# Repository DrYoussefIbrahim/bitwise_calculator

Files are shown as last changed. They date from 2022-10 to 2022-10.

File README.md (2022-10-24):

<html>

<h1> Bitwise Calculator Project </h1>
<subtitle> Author: Youssef Ibrahim - 24/October/2022 </subtitle>

<h2> Introduction </h2>
This is a pet project of mine where I aim to recreate the programming calcualtor function in Windows in hardware. The build features my favourite 5x7 LED matrices - the LTP-305G. The key matrix is based around the Cherry MX blue tactile keys for my pleasure.

<h2> Hardware description </h2>
This is a bare-board design as I prefer the minimalist aesthetic.

The hardware is dvided into two boards:
<ul>
<li> The key board - The main board. Houses the keys and microcontroller</li>
<li> The display board - Houses the LTP-305G modules and their drivers </li>
</ul>
The boards are combined into one PCB separated by a ratbite to simplify ordering from your favourite PCB fab house.

<h3> The key board </h3>
This sub-assembly consists of:
<ul>
<li> 21 Cherry MX blue tactile keys</li>
<li> The microcontroller - ATMEGA328PB (Of course!)</li>
<li> 74HC165 Parallel-in/Serial-out shift register - For key matrix multiplexing</li>
<li> Micro USB socket - for power only</li>
<li> I2C and power pads - for connection to the display board via a 4-core ribbon cable</li>
</ul>

<h3> The display board </h3>
This sub-assembly consists of:
<ul>
<li> 4 x IS31FL3730 LED matrix drivers - chained on a single I2C bus. All four I2C address configs are used</li>
<li> 8 x DIP 14 sockets - To receive the LTP-305G matricies</li>
<li> Power and I2C pads - To connect to the key board</li>
</ul>

<h2> Mode of operation </h2>
<p>The controller continously scans the key matrix using the 74HC165 shift register. Key inputs are parsed accordingly in software and the display is updated via the I2C interface. Simple, really! </p>

<p>All the magic happens in the software which implements the calculator function as well as drives the display animations. One of the keys on the key matrix is wired directly to the micro to serve as a wake-up interrupt since this isn't straight forward to implement using the shift register. This power-down feature is not currently implemented. </p>

<p> This project is still a work in progress. </p>

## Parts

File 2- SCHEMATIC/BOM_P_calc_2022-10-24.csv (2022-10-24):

ID | Name | Designator | Footprint | Quantity | Manufacturer Part | Manufacturer
1 | 1uF | C1 | C1206 | 1 | CL31B105KBHNNNE | SAMSUNG
2 | 4.7uF | C2 | C0402 | 1 | CL05A475MP5NRNC | SAMSUNG
3 | 100nF | C3,C4,C5,C8,C11,C12,C14,C16 | C0402 | 8 | CL05B104KB54PNC | Samsung Electro-Mechanics
4 | 10pF | C6,C7 | C0402 | 2 | CL05C100JB5NNNC | SAMSUNG
5 | 10uF | C9 | C1206 | 1 | CL31A106KBHNNNE | SAMSUNG
6 | BAS416,115 | D1,D2,D3,D4 | SOD-323_L1.8-W1.3-LS2.5-RD | 4 | BAS416,115 | Nexperia
7 | TPD4E05U06QDQARQ1 | D5 | USON-10_L2.5-W1.0-P0.50-BL | 1 | TPD4E05U06QDQARQ1 | TI
8 | 10kΩ | R1,R2,R3,R4,R5,R8,R9,R10,R11,R12,R13 | R0402 | 11 | 0402WGF1002TCE | UniOhm
9 | 1K | R6,R7 | R0402 | 2 | 0402WGF1001TCE | UniOhm
10 | DS1001-01-14BT1NSF6X-JKB | SK1,SK2,SK3,SK4,SK5,SK6,SK7,SK8 | DIP-14_L17.8-W10.2-P2.54-BL | 8 | DS1001-01-14BT1NSF6X-JKB | CONNFLY
11 | CHERRY MX BLUE | SW1,SW2,SW3,SW4,SW5,SW6,SW7,SW8,SW9,SW10,SW11,SW12,SW13,SW14,SW15,SW16,SW17,SW18,SW19,SW20,SW21 | CHERRY MX BLUE | 21
12 | ATMEGA328PB-AU | U1 | TQFP-32_L7.0-W7.0-P0.80-LS9.0-BL | 1 | ATMEGA328PB-AU | MICROCHIP
13 | 74HC165D,653 | U2 | SOIC-16_L9.9-W3.9-P1.27-LS6.0-BL | 1 | 74HC165D,653 | Nexperia
14 | IS31FL3730-QFLS2-TR | U3,U4,U5,U6 | QFN-24_L4.0-W4.0-P0.50-TL-EP2.7 | 4 | IS31FL3730-QFLS2-TR | Lumissil Microsystems
15 | 16MHz | X1 | OSC-SMD_4P-L3.2-W2.5-BL | 1 | X322516MLB4SI | YXC

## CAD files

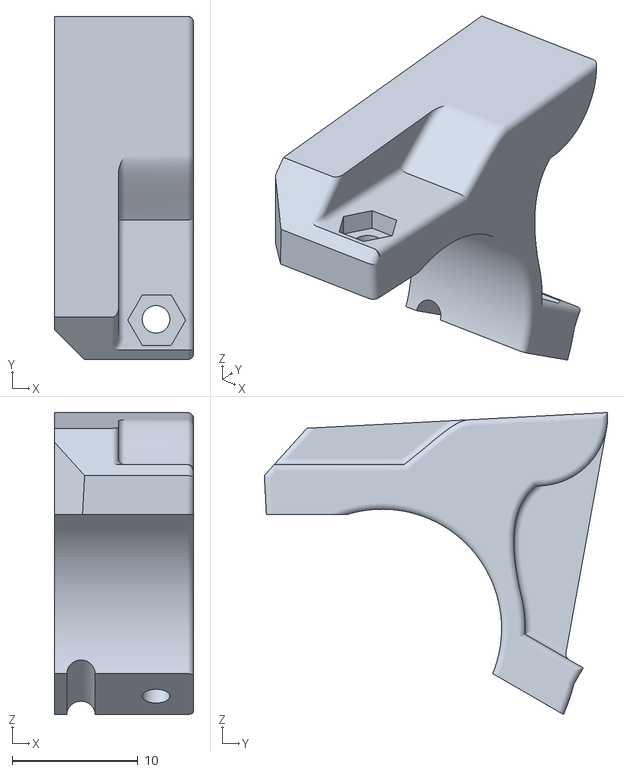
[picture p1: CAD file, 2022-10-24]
4- STL/LEFT SUPPORT(Mirror).stl
11.1 x 27.3 x 24.0

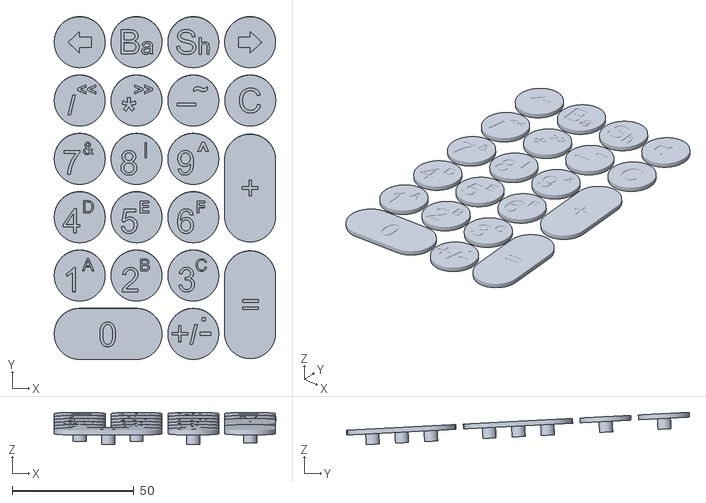
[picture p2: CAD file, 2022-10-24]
4- STL/P_calc_keys.stl
91.1 x 140.9 x 13.3

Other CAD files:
4- STL/RIGHT SUPPORT.stl

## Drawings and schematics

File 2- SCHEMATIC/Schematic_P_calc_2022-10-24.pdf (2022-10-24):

# DS 10 D0 11 D1 12 D2 13 D3 14 CE# 15 VCC 16

# Shift Register

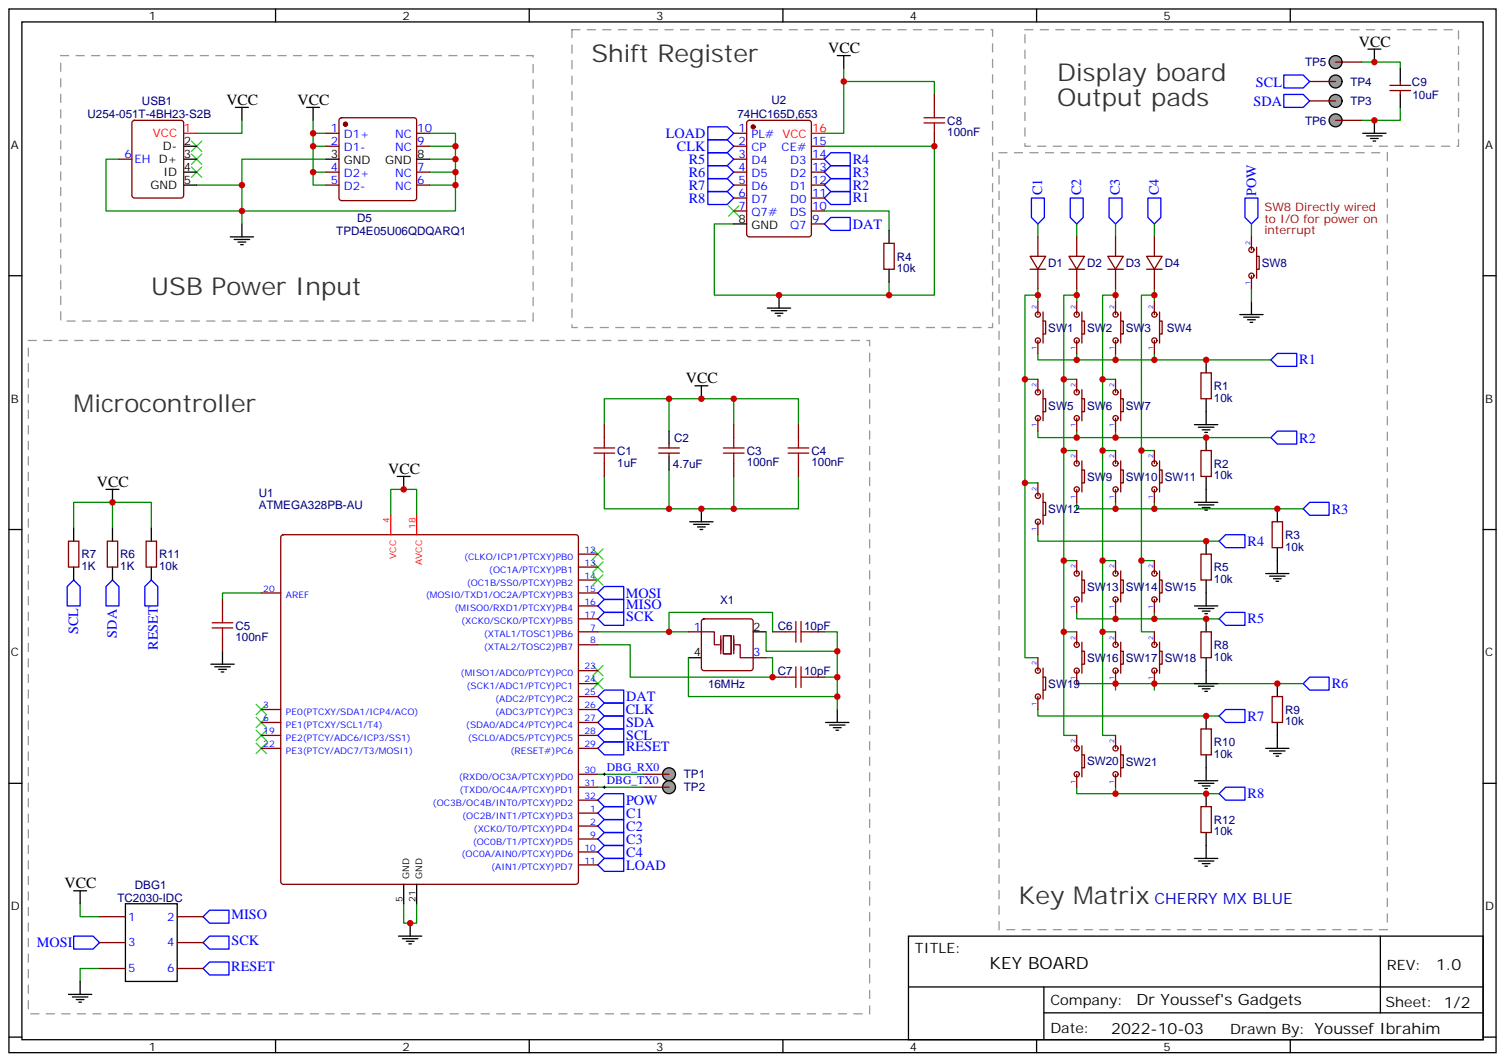
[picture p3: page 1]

SW8 Directly wired
to I/O for power on
interrupt

Key Matrix CHERRY MX BLUE

Company: Dr Youssef's Gadgets

Drawn By: Youssef Ibrahim

# LED Matrices 1 and 2

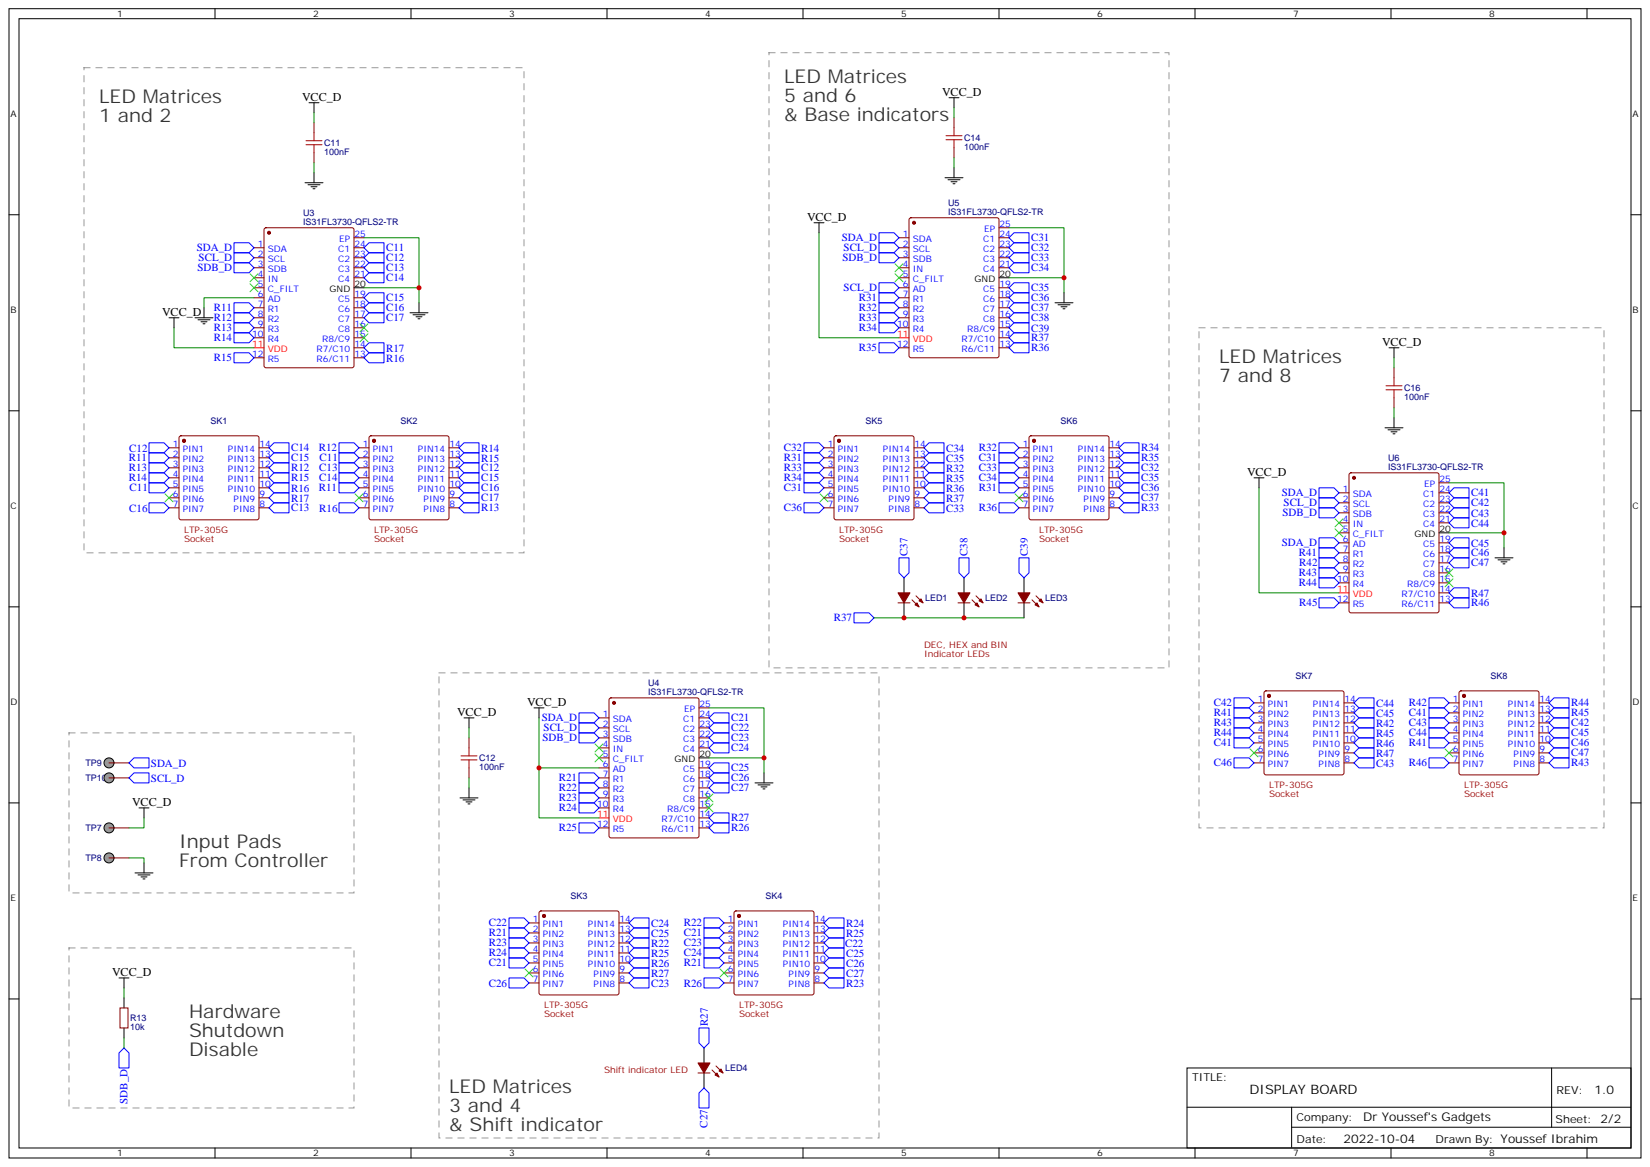
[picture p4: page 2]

DEC, HEX and BIN
Indicator LEDs

Company: Dr Youssef's Gadgets

Drawn By: Youssef Ibrahim

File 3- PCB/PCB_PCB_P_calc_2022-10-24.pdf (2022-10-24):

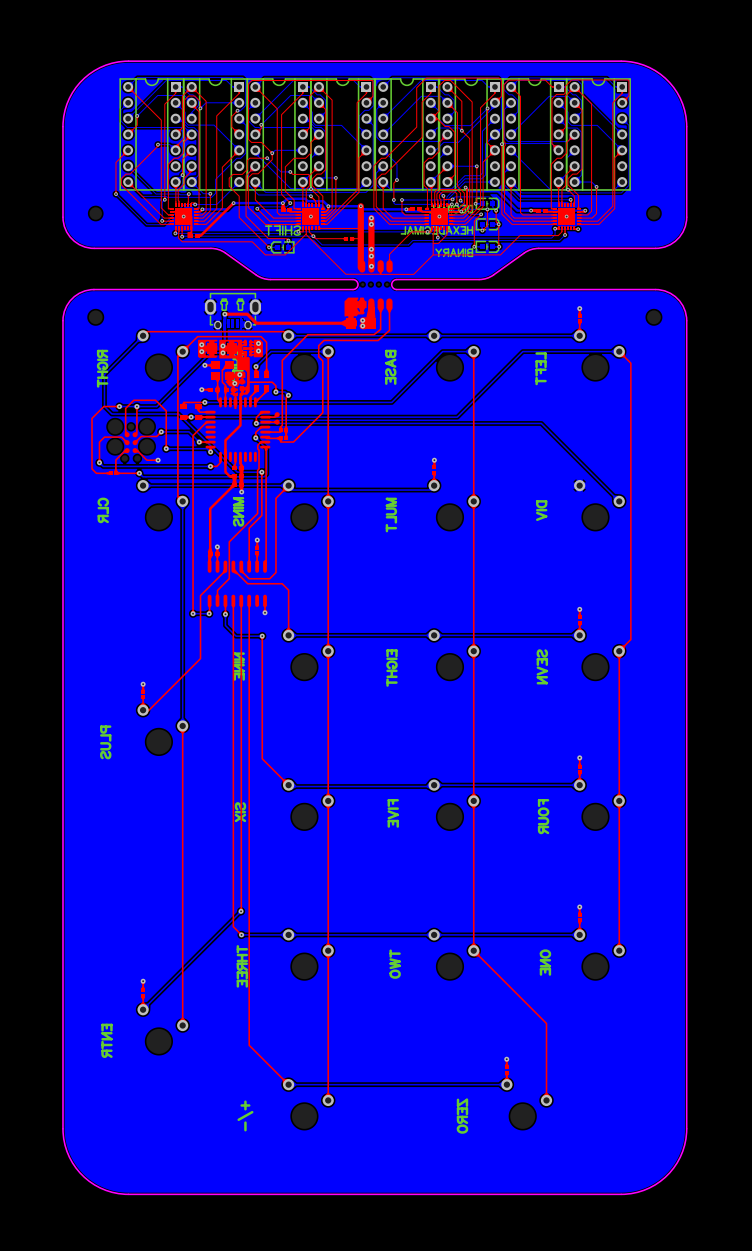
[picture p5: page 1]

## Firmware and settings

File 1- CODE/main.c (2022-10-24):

/*

Created: 12/10/2022 16:50:48
Author : Youssef Ibrahim

Bitwise Claculator (c) by Youssef Ibrahim

Bitwise Claculator is licensed under a
Creative Commons Attribution-ShareAlike 4.0 International License.

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
*/

#define F_CPU 16000000UL

#include <avr/io.h>
#include <util/delay.h>
#include <avr/interrupt.h>
#include "IS31FL3730.h"
#include "key_matrix.h"

void update_reg();
volatile uint8_t head = 10;
volatile uint8_t view = 10;
volatile uint32_t reg = 0;
volatile uint32_t regB = 0;
uint32_t regC = 0;
uint8_t valid = 0;
volatile uint8_t operation = 0;
volatile uint8_t execute = 0;

ISR(INT0_vect) {
	EIMSK &= ~0b00000001;
	if(shift_state == 1){
		reg <<= 1;
		update_reg();
		EIMSK |= 0b00000001;
		} else {
		operation = 4;
		execute = 0;
		regB = reg;
		IS31_clear();
		view = 10;
		head = 10;
		reg = 0;
	}
}

int main(void)
{
	TWI_Setup();
	EICRA = 0b00000000;
	EIMSK = 0b00000001;
	sei();
	IS31_begin();
	IS31_setMaxCurrent(11);
	IS31_setBrightness(128);
	key_begin();
	IS31_setBase(1);
	
	while (1)
	{
		while(key_scan() == -1);
		TWI_Reset();
		
		uint8_t key_input= key_scan();
		
		switch(key_input){
			case 10:
			break;
			
			case 11:
			if(execute != 1){
				regC = reg;
				execute = 1;
			}
			switch(operation){
				case 0:
				break;
				
				case 1: // Add
				regB += regC;
				break;
				
				case 2: // Multiply
				regB *= regC;
				break;
				
				case 3: // Subtract
				if(regB > regC){
					regB -= regC;
					} else {
					regB = 0;
				}
				break;
				
				case 4:
				regB /= regC;
				EIMSK = 0b00000001;
				break;
				
				case 5: // Bitwise AND
				regB &= regC;
				break;
				
				case 6: // Bitwise OR
				regB |= regC;
				break;
				
				case 7: // Bitwise XOR
				regB ^= regC;
				break;
				
				case 8: // Modulo
				regB %= regC;
				break;
				
				default:
				break;
			}
			reg = regB;
			update_reg();
			EIMSK = 0b00000001;
			break;
			
			case 12:
			operation = 1;
			execute = 0;
			regB = reg;
			IS31_clear();
			view = 10;
			head = 10;
			reg = 0;
			break;
			
			case 13:
			if(shift_state == 1){
				reg >>= 1;
				update_reg();
				} else {
				operation = 2;
				execute = 0;
				regB = reg;
				IS31_clear();
				view = 10;
				head = 10;
				reg = 0;
			}
			break;
			
			case 14:
			if(shift_state == 1){
				uint8_t mx = 0;
				uint32_t scanner = 1;
				for(uint8_t bt = 0; bt < 32 ; bt++){
					if(reg & (scanner<<bt)){
						mx = bt;
					}
				}
				mx++;
				scanner = 1;
				while(mx < 32){
					reg |= (scanner<<mx);
					mx++;
				}
				reg = ~reg;
				update_reg();
				} else {
				operation = 3;
				execute = 0;
				regB = reg;
				IS31_clear();
				view = 10;
				head = 10;
				reg = 0;
			}
			break;
			
			case 15:
			if(shift_state == 0){
			IS31_clear();
			view = 10;
			IS31_Update(view);
			head = 10;
			reg = 0;
			regB = 0;
			regC = 0;
			execute = 0;
			operation = 0;
			EIMSK = 0b00000001;
			} else {
				operation = 8;
				execute = 0;
				regB = reg;
				IS31_clear();
				view = 10;
				head = 10;
				reg = 0;
			}
			break;
			
			case 16:
			if(view<129 && (view + 40) < head){
				for(uint8_t i = 0; i < 5; i++){
					view++;
					IS31_Update(view);
					_delay_ms(10);
				}
			}
			break;
			
			case 17:
			IS31_setBase(base_state == 3? 1 : base_state + 1);
			update_reg();
			break;
			
			case 18:
			IS31_shift(!shift_state);
			break;
			
			case 19:
			if(view>=15){
				for(uint8_t i = 0; i < 5; i++){
					view--;
					IS31_Update(view);
					_delay_ms(10);
				}
			}
			break;
			
			default:
			valid = 0;
			if(shift_state == 1 && key_input > 6 ){
				switch(key_input){
					case 7:
					operation = 5;
					execute = 0;
					regB = reg;
					IS31_clear();
					view = 10;
					head = 10;
					reg = 0;
					break;
					
					case 8:
					operation = 6;
					execute = 0;
					regB = reg;
					IS31_clear();
					view = 10;
					head = 10;
					reg = 0;
					break;
					
					case 9:
					operation = 7;
					execute = 0;
					regB = reg;
					IS31_clear();
					view = 10;
					head = 10;
					reg = 0;
					break;
					
					default:
					break;
				}
			} else {
				switch(base_state){
					case 1:
					if(shift_state == 0 || key_input == 0){
						reg = (reg * 10) + key_input;
						IS31_drawChar(5, key_input);
						valid = 1;
					}
					break;
					
					case 2:
					if(shift_state == 0 || key_input == 0){
						reg = (reg * 16) + key_input;
						IS31_drawChar(5, key_input);
						valid = 1;
						} else if(key_input <= 6){
						reg = (reg * 16) + (key_input + 9);
						IS31_drawChar(5, key_input + 9);
						valid = 1;
					}
					break;
					
					case 3:
					if(key_input <= 1){
						reg = (reg * 2) + key_input;
						IS31_drawChar(5, key_input);
						valid = 1;
					}
					break;
				}
			}
			
			if(valid == 1){
				for(uint8_t i = 0; i < 5; i++){
					head++;
					IS31_scrollLeft();
					IS31_Update(view);
					_delay_ms(10);
				}
			}
			break;
		}
		
		while(key_scan() != -1);
	}
}

void update_reg(){
	for(uint8_t i = 0; i < 7; i++){
		IS31_scrollUp();
		IS31_Update(view);
		_delay_ms(10);
	}
	
	view = 10;
	if(reg != 0){
		for(uint8_t j = 0; j < 7; j++){
			head = 10;
			IS31_clear();
			uint32_t reg_temp = reg;
			uint32_t divisor = 1;
			uint8_t base = 0;
			switch(base_state){
				case 1:
				base = 10;
				break;
				
				case 2:
				base = 16;
				break;
				
				case 3:
				base = 2;
				break;
				
				default:
				break;
			}
			while(divisor <= (reg / base)){
				divisor *= base;
			}
			while(divisor > 0){
				for(uint8_t i = 0; i < 5; i++){
					IS31_scrollLeft();
					head++;
				}
				IS31_drawChar(10, reg_temp / divisor);
				reg_temp %= divisor;
				divisor /= base;
			}
			for(uint8_t k = 0; k < 6 - j; k++){
				IS31_scrollDown();
			}
			IS31_Update(view);
		}
	}
}

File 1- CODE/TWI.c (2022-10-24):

#include "TWI.h"

#define __TWI_SLA_W(address)	(address<<1)
#define __TWI_SLA_R(address)	((address<<1) | (1<<0))

#define F_CPU 16000000UL
//----- Prototypes ------------------------------//

//-----------------------------------------------//

//----- Functions -------------//
//Setup TWI hardware.
void TWI_Setup(void)
{
	//TWI pins as outputs
	PinMode(TWI_SDA, Output);
	PinMode(TWI_SCL, Output);
	//Activate internal pull-up resistors
	DigitalWrite(TWI_SDA, High);
	DigitalWrite(TWI_SCL, High);

	//Initialize TWI prescaler and bit rate
	TWSR0 = 0x00;	//Prescaler = 1
	TWBR0 = (uint8_t)(((F_CPU / F_SCL) - 16) / 2);
	//F_SCL = F_CPU / (16 + 2 * TWBR0 * PRESCALER)
	//TWBR0 = ((F_CPU / F_SCL) - 16) / (2 * PRESCALER)

	//Enable TWI  module
	TWCR0 = (1<<TWEN);
}

//Get TWI status. 
uint8_t TWI_Status(void)
{
	return (TWSR0 & 0xF8);
}

//Begin TWI transmission. 
uint8_t TWI_BeginTransmission(void)
{
	uint16_t i2c_count = 0;
	//Transmit START condition
	TWCR0 = (1<<TWINT) | (1<<TWSTA) | (1<<TWEN);

	//Wait for TWINT Flag set. This indicates that
	//the START condition has been transmitted.
	while ((!BitCheck(TWCR0, TWINT)) && (i2c_count < i2c_timeout)){
		i2c_count++;
	}

	//Return status register
	return (TWI_Status());
}

//End TWI transmission. 
void TWI_EndTransmission(void)
{
	uint16_t i2c_count = 0;
	//Transmit STOP condition
	TWCR0 = (1<<TWEN) | (1<<TWIE) | (1<<TWEA) | (1<<TWINT) | (1<<TWSTO);

	//Wait for stop condition to be executed on bus
	//TWINT is not set after a stop condition!
	while((BitCheck(TWCR0, TWSTO)) && (i2c_count < i2c_timeout)){
		i2c_count++;
	}
}

//Transmit data. 
uint8_t TWI_Transmit(const uint8_t Data)
{
	uint16_t i2c_count = 0;
	//Data to be transmitted
	TWDR0 = Data;

	//Start transmission
	TWCR0 = (1<<TWINT) | (1<<TWEN);

	//Wait data to be shifted
	while ((!BitCheck(TWCR0, TWINT)) && (i2c_count < i2c_timeout)){
		i2c_count++;
	}

	//Return status register
	return (TWI_Status());
}

//Wait until ACK received. 
uint8_t TWI_ReceiveACK(void)
{
	uint16_t i2c_count = 0;
	TWCR0 = (1<<TWINT) | (1<<TWEA) | (1<<TWEN);
	
	//Wait till reception is
	while ((!BitCheck(TWCR0, TWINT)) && (i2c_count < i2c_timeout)){
		i2c_count++;
	}

	//Return received data
	return TWDR0;
}

//Wait until NACK received. 
uint8_t TWI_ReceiveNACK(void)
{
	uint16_t i2c_count = 0;
	TWCR0 = (1<<TWINT) | (1<<TWEN);

	//Wait till reception is
	while ((!BitCheck(TWCR0, TWINT)) && (i2c_count < i2c_timeout)){
		i2c_count++;
	}

	//Return received data
	return TWDR0;
}

//Transmit packet to specific slave address. 
enum TWI_Status_t TWI_PacketTransmit(const uint8_t SLA, const uint8_t SubAddress, uint8_t *Packet, const uint8_t Length)
{
	uint8_t i, status;
	
	do
	{
		//Transmit START signal
		status = TWI_BeginTransmission();
		if ((status != MT_START_TRANSMITTED) && ((status != MT_REP_START_TRANSMITTED)))
		{
			status = TWI_Error;
			break;
		}

		//Transmit SLA+W
		status = TWI_Transmit(__TWI_SLA_W(SLA));
		if ((status != MT_SLA_W_TRANSMITTED_ACK) && (status != MT_SLA_W_TRANSMITTED_NACK))
		{
			status = TWI_Error;
			break;
		}

		//Transmit write address
		status = TWI_Transmit(SubAddress);
		if ((status != MT_DATA_TRANSMITTED_ACK) && (status != MT_DATA_TRANSMITTED_NACK))
		{
			status = TWI_Error;
			break;
		}
		//Transmit DATA
		for (i = 0 ; i < Length ; i++)
		{
			status = TWI_Transmit(Packet[i]);
			if ((status != MT_DATA_TRANSMITTED_ACK) && (status != MT_DATA_TRANSMITTED_NACK))
			{
				status = TWI_Error;
				break;
			}
		}

		//Transmitted successfully
		status = TWI_Ok;
	}
	while (0);

	//Transmit STOP signal
	TWI_EndTransmission();

	return status;
}

//Receive packet from specific slave address. 
enum TWI_Status_t TWI_PacketReceive(const uint8_t SLA, const uint8_t SubAddress, uint8_t *Packet, const uint8_t Length)
{
	uint8_t i = 0, status;

	do 
	{
		//Transmit START signal
		status = TWI_BeginTransmission();
		if ((status != MT_START_TRANSMITTED) && (status != MT_REP_START_TRANSMITTED))
		{
			status = TWI_Error;
			break;
		}

		//Transmit SLA+W
		status = TWI_Transmit(__TWI_SLA_W(SLA));
		if ((status != MT_SLA_W_TRANSMITTED_ACK) && (status != MT_SLA_W_TRANSMITTED_NACK))
		{
			status = TWI_Error;
			break;
		}

		//Transmit read address
		status = TWI_Transmit(SubAddress);
		if ((status != MT_DATA_TRANSMITTED_ACK) && (status != MT_DATA_TRANSMITTED_NACK))
		{
			status = TWI_Error;
			break;
		}

		//Transmit START signal
		status = TWI_BeginTransmission();
		if ((status != MR_START_TRANSMITTED) && (status != MR_REP_START_TRANSMITTED))
		{
			status = TWI_Error;
			break;
		}

		//Transmit SLA+R
		status = TWI_Transmit(__TWI_SLA_R(SLA));
		if ((status != MR_SLA_R_TRANSMITTED_ACK) && (status != MR_SLA_R_TRANSMITTED_NACK))
		{
			status = TWI_Error;
			break;
		}

		//Receive DATA
		//Read all the bytes, except the last one, sending ACK signal
		for (i = 0 ; i < (Length - 1) ; i++)
		{
			Packet[i] = TWI_ReceiveACK();
			status = TWI_Status();
			if ((status != MR_DATA_RECEIVED_ACK) && (status != MR_DATA_RECEIVED_NACK))
			{
				status = TWI_Error;
				break;
			}
		}
		//Receive last byte and send NACK signal
		Packet[i] = TWI_ReceiveNACK();
		status = TWI_Status();
		if ((status != MR_DATA_RECEIVED_ACK) && (status != MR_DATA_RECEIVED_NACK))
		{
			status = TWI_Error;
			break;
		}

		//Received successfully
		status = TWI_Ok;
	} 
	while (0);

	//Transmit STOP signal
	TWI_EndTransmission();
	
	return status;
}

//Set self slave address.
void TWI_SetAddress(const uint8_t Address)
{
	//Set TWI slave address (upper 7 bits)
	TWAR0 = Address<<1;
}
//-----------------------------//

void TWI_Reset(){
	TWCR0 &= !(1<<TWEN);
	TWCR0 |= (1<<TWEN);
}

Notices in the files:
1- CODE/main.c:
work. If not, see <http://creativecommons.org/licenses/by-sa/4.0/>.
